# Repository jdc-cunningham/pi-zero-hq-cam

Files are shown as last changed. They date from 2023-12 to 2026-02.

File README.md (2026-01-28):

### About

#### Ver 1.1.0

A pi zero (1/2) camera body using the hq camera

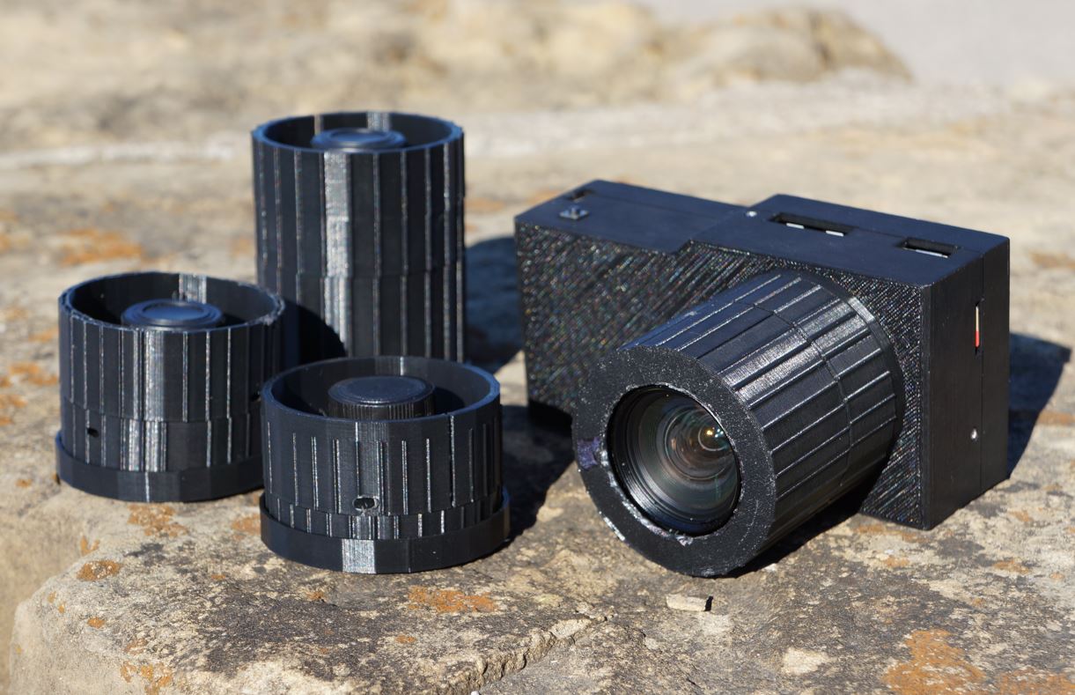
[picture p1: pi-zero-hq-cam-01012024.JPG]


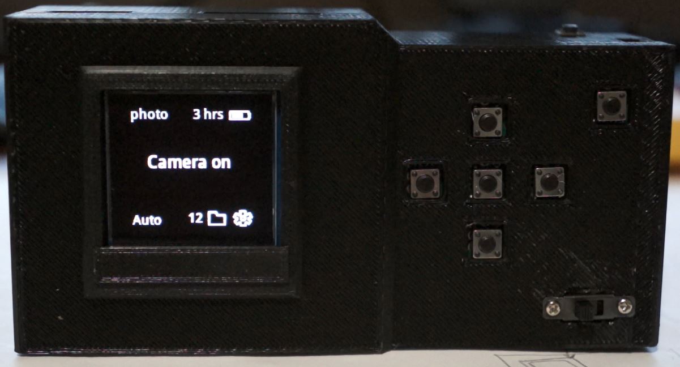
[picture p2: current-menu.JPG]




### Who is this camera for?

This camera is not about quality. You obviously can't compare this to a real camera eg. a Sony Alpha. This camera is about writing your own software/a stepping stone for other camera designs.

#### Example photo

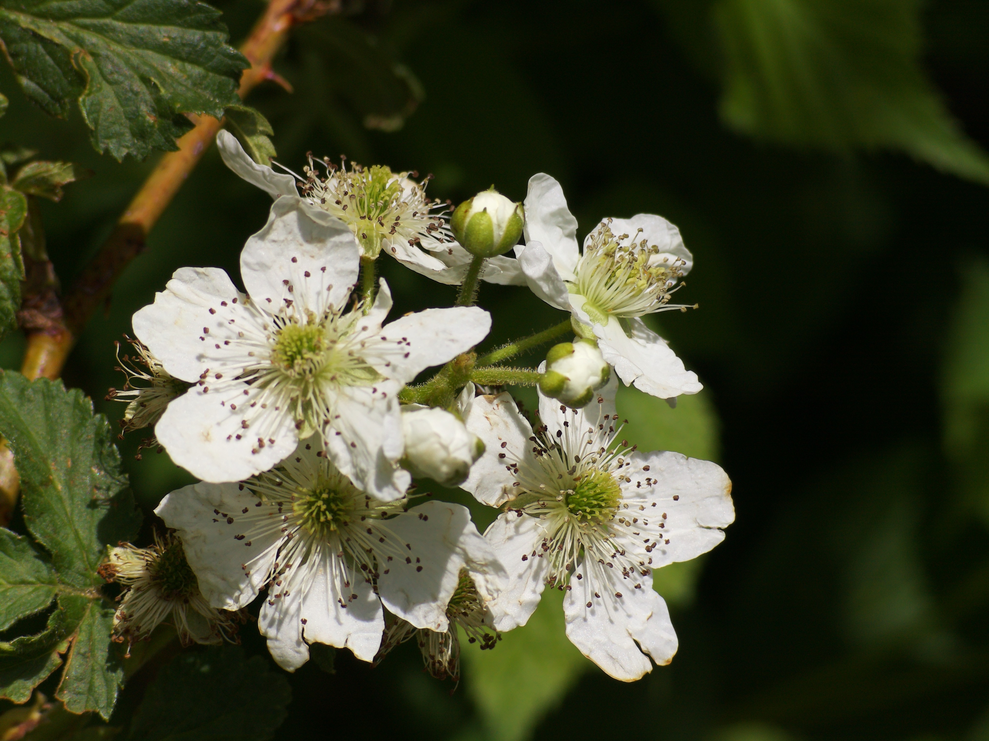
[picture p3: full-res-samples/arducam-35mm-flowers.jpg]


[full res samples](./full-res-samples/)

### Features

[See list](./camera/software/FEATURES.md) and [Changelog](./CHANGELOG.md)

### Estimated cost

$93.00 (no lens, major components only)

See `/camera/hardware` folder for more info

### Disclaimer

The 5V 1A micro usb charger's discharge cut off is very low around 2.5V, keep that in mind depending on your battery.

### Note

Refer to the [modular pi cam's software](https://github.com/jdc-cunningham/modular-pi-cam/tree/master/cameras/pi-zero/large-display/software) which is more current than this.

Eventually [pelicam](https://github.com/jdc-cunningham/pelicam) will be the general purpose DIY camera software

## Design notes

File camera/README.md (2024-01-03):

### About

- body (3D models)
- hardware (wiring diagrams)
- software (code)

### Lenses used so far

- Cytron 12mm CS mount F1.8 (prime)
- Cytron 35mm C mount F1.7 to F16 (prime)
- Amazon Sonew 5mm C mount F1.6 to F16 (prime)
- Utronics Arducam 8-50mm c-mount F1.4 adjustable (zoom)

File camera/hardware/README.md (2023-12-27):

### Parts list

- $15.00 Pi Zero W
- $75.00 Raspberry Pi HQ Camera
- $2.00 720mAh 1S Lipo
- $0.80 DC-DC boost converter
- $0.80 5V 1A usb charger
- $0.12 LD33V step down converter
- $19.00 1.5" RGB OLED
- $60.00 35mm lens
- $32 12mm lens
- $60 5mm lens
- $10 GY-91 10-axis IMU

#### Alternate parts

- $9 18650 cell - 3400mAh 4.9A discharge
- $14.33 mEZD41503A-A step-up converter 5V@3A

M1.7*6 screws

### Part layout

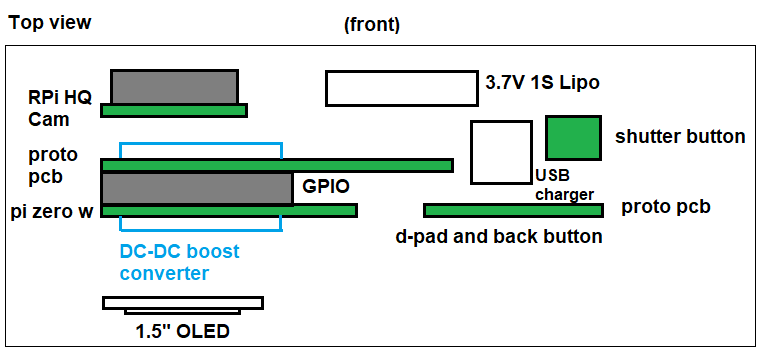
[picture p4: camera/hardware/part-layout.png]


### Pin out/wiring

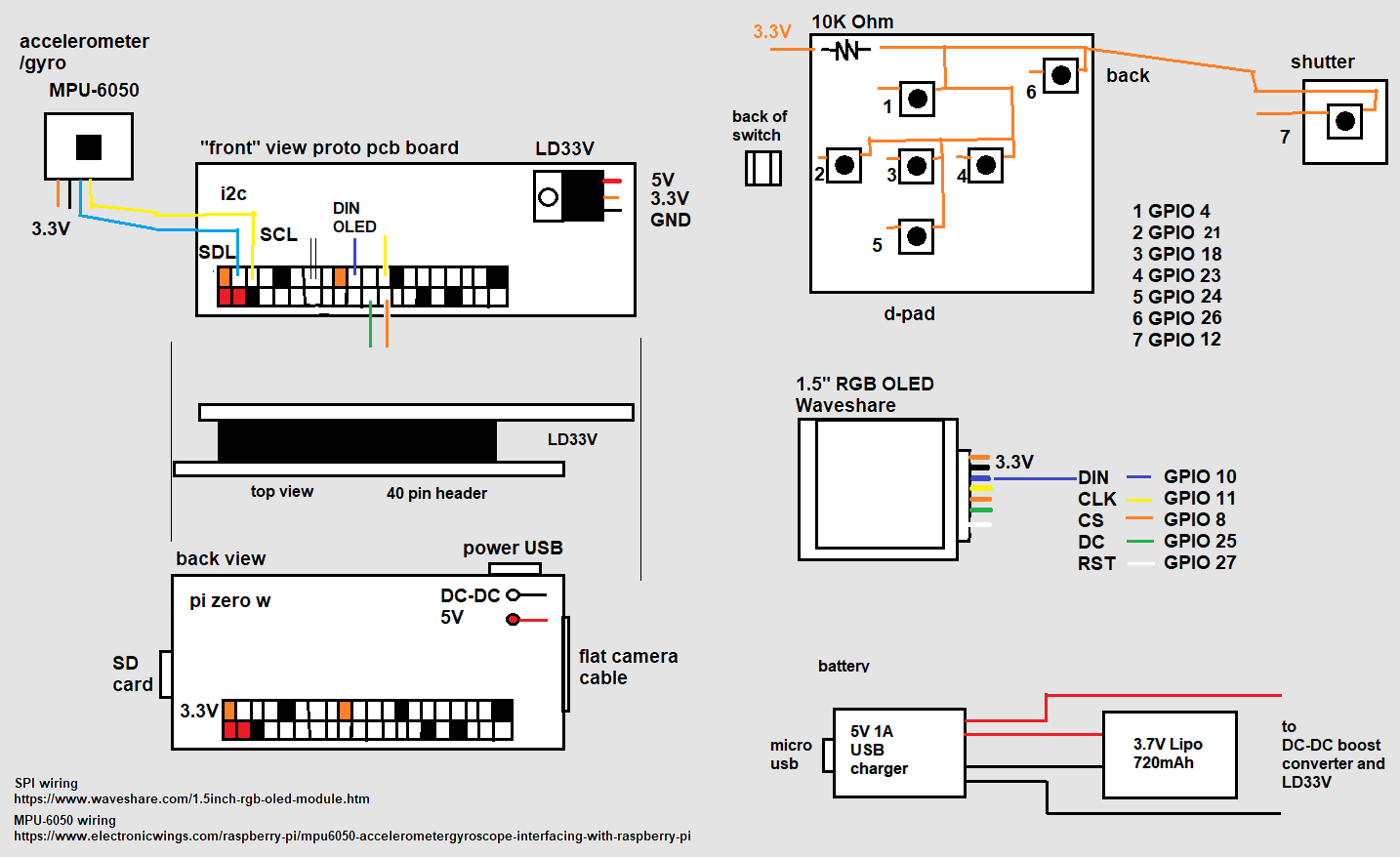
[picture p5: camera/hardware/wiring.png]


### D-pad, back and shutter buttons

### Pi Zero (1/2) GPIO mappings

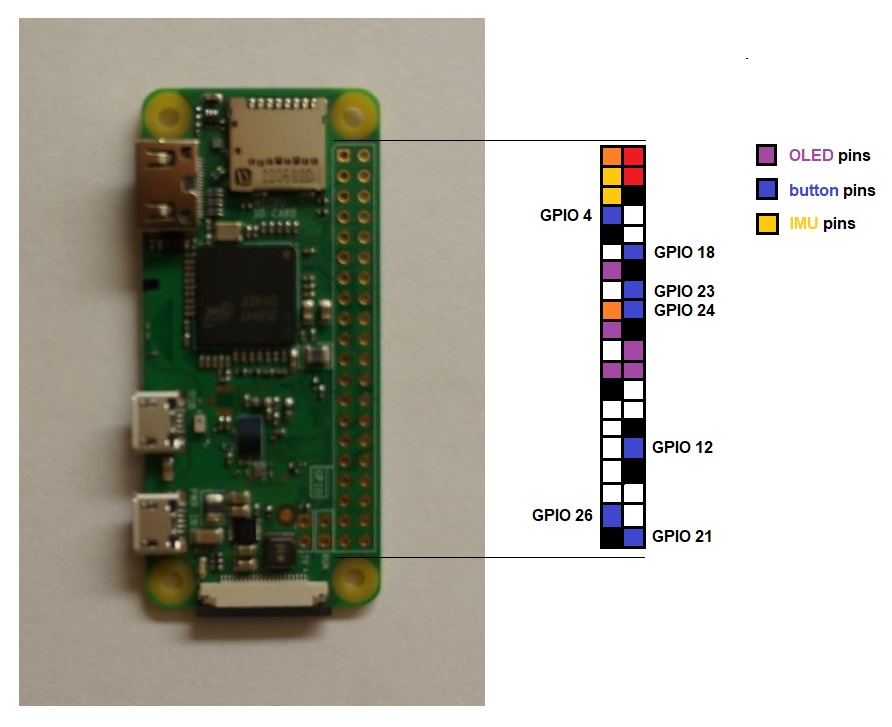
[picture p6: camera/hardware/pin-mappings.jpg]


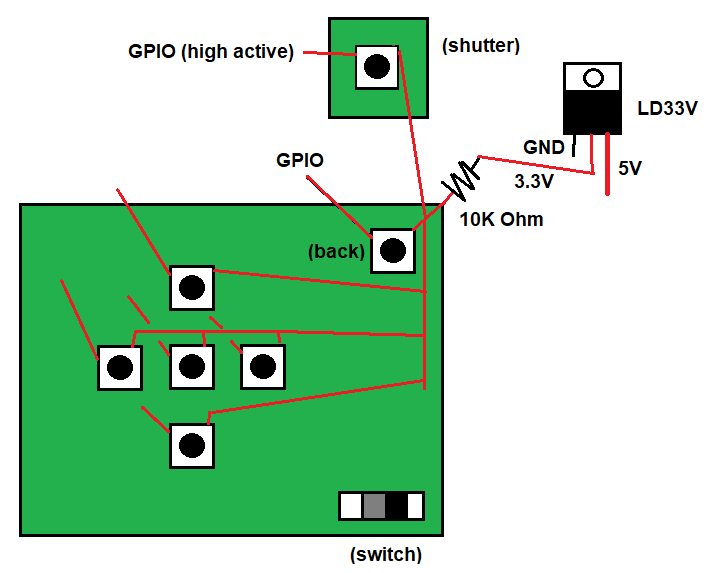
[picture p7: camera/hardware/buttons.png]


### Assembly order

- camera board (remove lens, screw, goes in from inside)
- imu (screw)
- shutter (glue)
- charger board (glue)
- battery (double sided foam tape or some glue/free floating)
- DC-DC free floating
- OLED (screws)
- push switch through (may have to bend ends temporarily, screw)
- dpad (glue)
- solder pi to hanger screw mount

join two halves together, 4 screws

### Future

A USB mic/stereo that can get plugged into the exposed USB port too add audio in/out

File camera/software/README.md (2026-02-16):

### Current code overview

See the video below

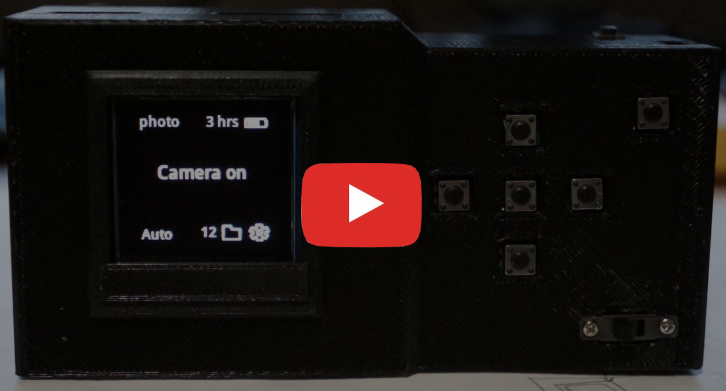
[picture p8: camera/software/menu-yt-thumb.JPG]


### Note on FPS

Please note that this code uses image capture vs. streaming which may be way faster. Check out this [mjpeg_server sample code](https://github.com/raspberrypi/picamera2/blob/main/examples/mjpeg_server.py).

### Deps

- need SPI enabled (raspi-config)
- need pip3, smbus (via pip)

### Boot script

There is a boot script that runs `main.py` in the `software` folder

It uses systemd, see the basic service file below below (systemd service)

Create a file named `pi-cam.service` in the `/etc/systemd/system/` folder

```
[Unit]
Description=Start Pi Cam
After=multi-user.target

[Service]
Type=idle
WorkingDirectory=/home/pi/pi-zero-hq-cam/camera/software
User=pi
ExecStart=/usr/bin/python3 /home/pi/pi-zero-hq-cam/camera/software/main.py
Restart=no

[Install]
WantedBy=multi-user.target
Commands for myself
```

Add the service

```
$sudo nano /etc/systemd/system/pi-cam.service
$sudo systemctl enable pi-cam.service
$sudo systemctl daemon-reload
$sudo systemctl restart pi-cam.service
```

Verify it's working with

`$sudo systemctl status pi-cam.service`

### Development notes

As of this time I have not found a way to mount/develop against the Pi. I also have not mocked the features eg. OLED, etc... to run on say a Windows computer.

I am using SFTP to edit files on the pi and then run the code via ssh session

### Battery profiling

`*/5 * * * * /usr/bin/python /home/pi/pi-zero-hq-cam/camera/software/cron_battery_ticker.py >> /home/pi/cron-battery-ticker.log 2>&1`

Verify python binary location via `$which python`

There is a Sqlite database `battery.db` that keeps track of the camera's uptime and a CRON job that increments a DB entry every 5 minutes.

In the settings menu there is a `battery profiler` function which you would run after fully charging your pi cam.

It is a loose estimate since it does not reflect how many times the user has turned the live preview on/off... it's about 75% of max capacity... based 50% testing eg. 50% preview on/off before camera dies + 25% of that to be under 80% battery usage.

I had measured some current draw values before based on what the camera is doing but I did not do a good job/accurately do it, plus the electronics changed since then. But the highest current draw is during live camera preview eg. around 600mA. For reference the pi zero 1 would draw around 65mA during idle.

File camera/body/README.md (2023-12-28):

### Print times

- 8 hrs body front
- 6 hrs body back
- 35mm aperture ring - 2.5 hrs
- 35mm focus ring - 4.5 hrs

20% infill, supports, PLA, 50mm/s print speed

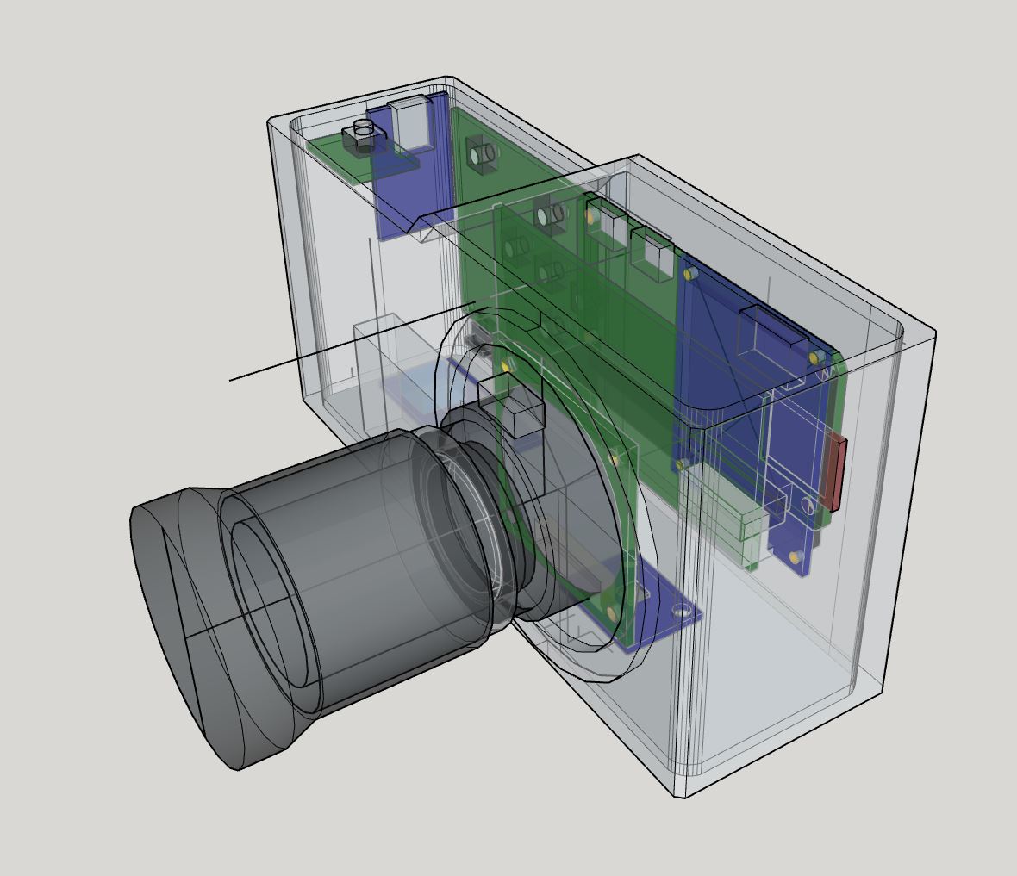
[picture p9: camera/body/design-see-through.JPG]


### Lenses

- 5mm sonew
  - this is the best "all around" lens since it's 27.5mm full frame equivalent
- 12mm arducam
  - this is used as a macro lens
- 35mm arducam
  - narrow due to the 5.5 crop factor
- 8-50mm arducam
  - this works best with the Arducam camera IMX477 camera
  - depending on which adapter is used the lens works better close or far eg. rpi adapter vs. 2 c-cs adapters (hence multiple stl files)

The 8-50mm uses 2 ring adapters (shorter). The other 3 use the RPi HQ Cam ring adapter.

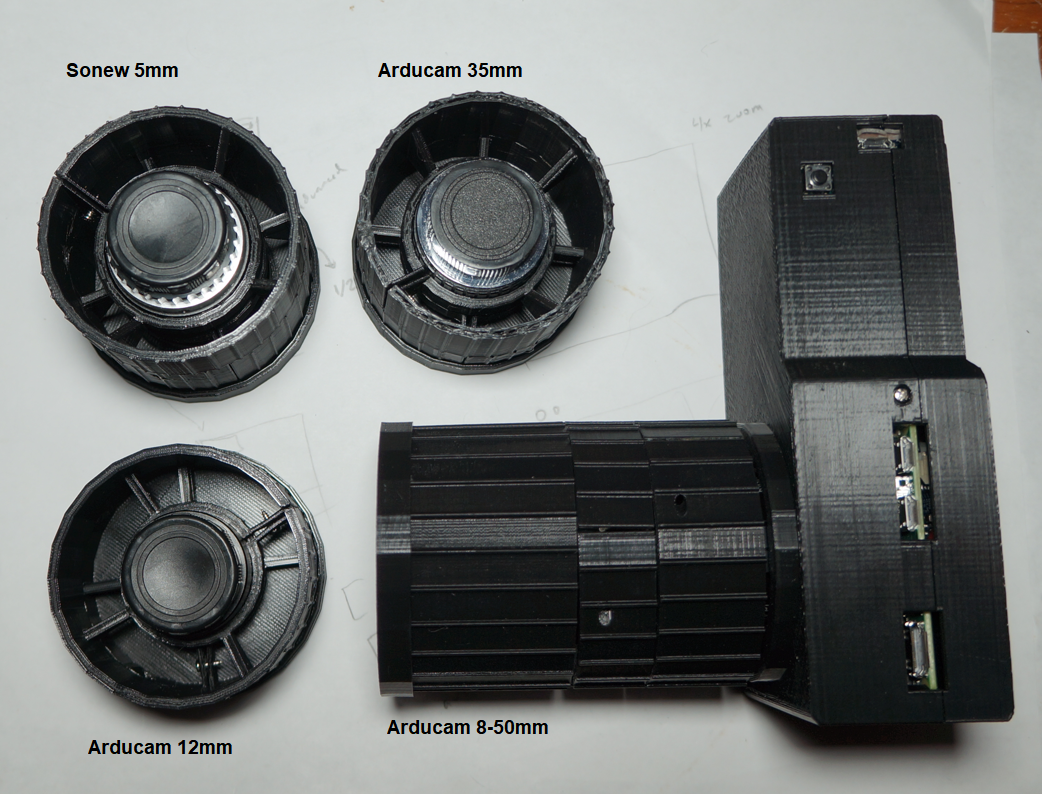
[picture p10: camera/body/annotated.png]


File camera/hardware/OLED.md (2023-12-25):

wiring guide

https://www.waveshare.com/1.5inch-rgb-oled-module.htm

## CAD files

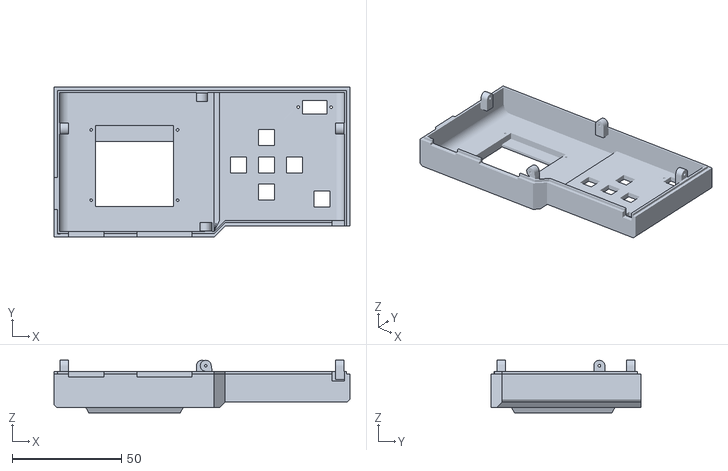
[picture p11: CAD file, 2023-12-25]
camera/body/3d-models/stls/camera-body/body-back.stl
135.2 x 68.6 x 24.0

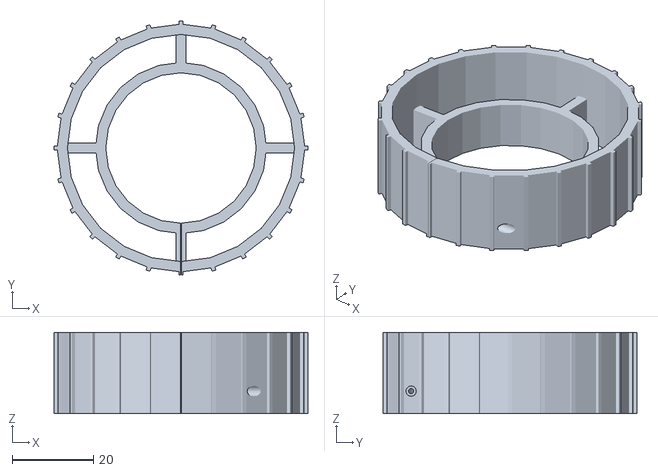
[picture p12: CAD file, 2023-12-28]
camera/body/3d-models/stls/lens/8-50mm-arducam-telephoto-focus-ring-1-rpi-adapter-ring.stl
62.5 x 62.5 x 20.0

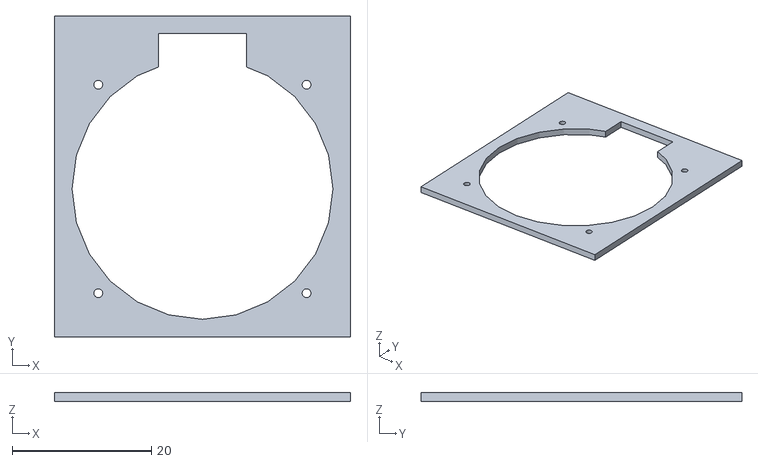
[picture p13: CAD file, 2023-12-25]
camera/body/3d-models/stls/test-fit-camera.stl
42.6 x 46.1 x 1.27

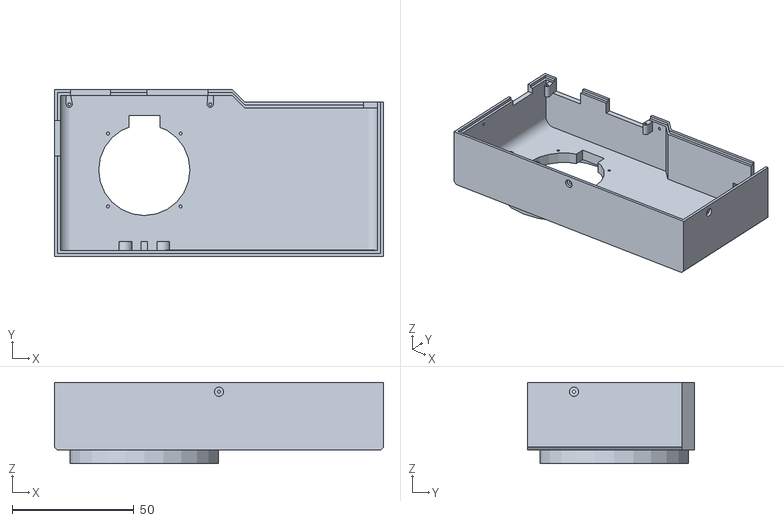
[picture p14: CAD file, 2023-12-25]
camera/body/3d-models/stls/camera-body/body-front.stl
135.2 x 68.6 x 33.3

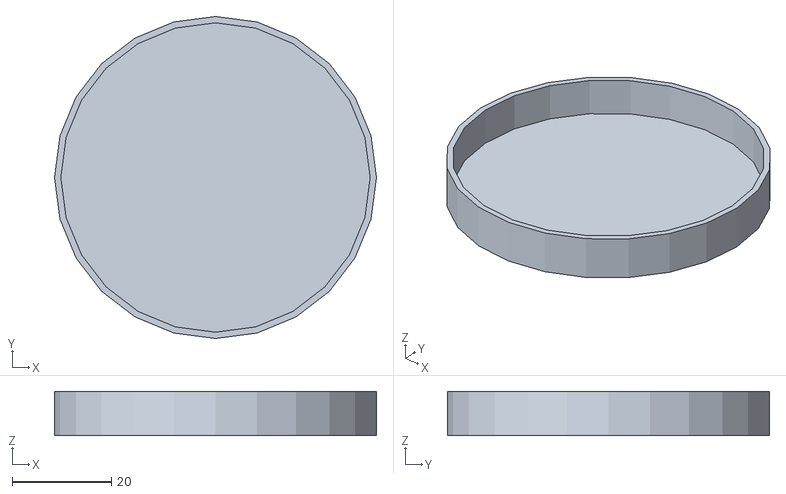
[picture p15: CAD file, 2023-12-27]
camera/body/3d-models/stls/lens/12mm-arducam-lens-cap.stl
64.8 x 64.8 x 8.89

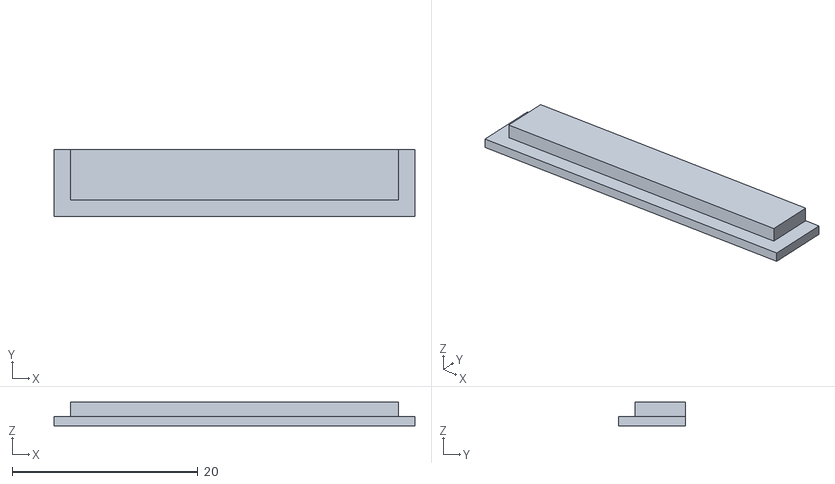
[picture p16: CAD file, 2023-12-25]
camera/body/3d-models/stls/oled-bottom-cover.stl
38.9 x 7.21 x 2.54

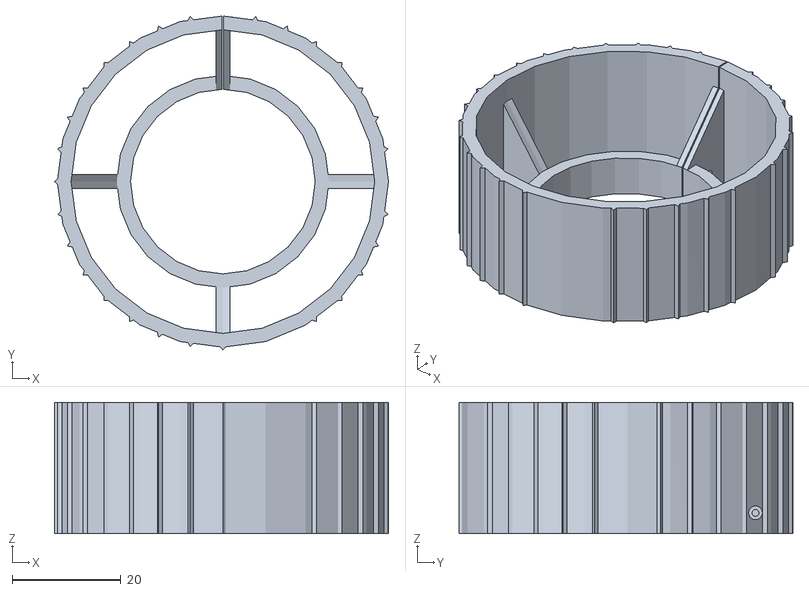
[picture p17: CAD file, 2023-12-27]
camera/body/3d-models/stls/lens/35mm-arducam-aperture-ring.stl
61.5 x 61.5 x 24.1

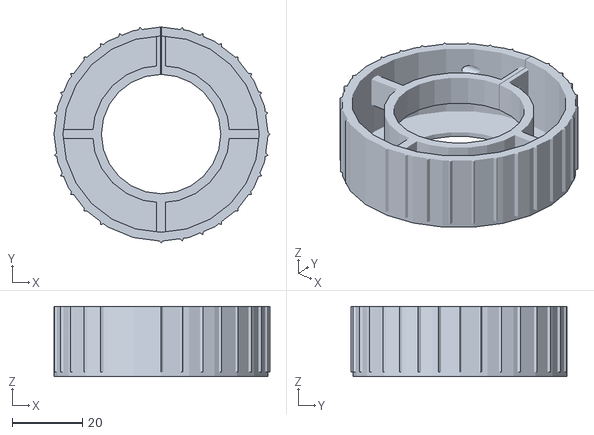
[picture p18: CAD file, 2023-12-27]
camera/body/3d-models/stls/lens/35mm-arducam-focus-ring.stl
61.5 x 61.5 x 20.0

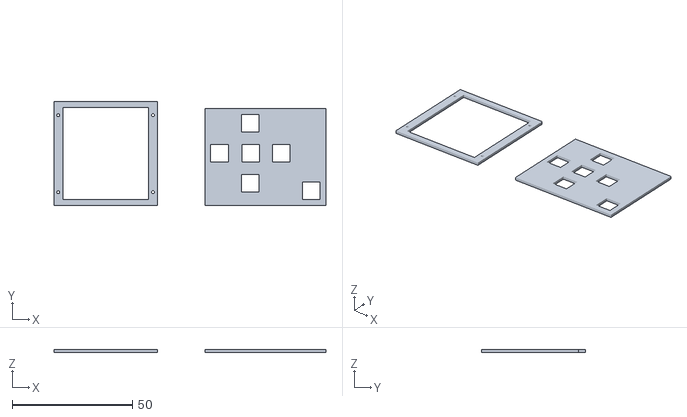
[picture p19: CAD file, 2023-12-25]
camera/body/3d-models/stls/test-fit-back.stl
113.3 x 43.4 x 1.29

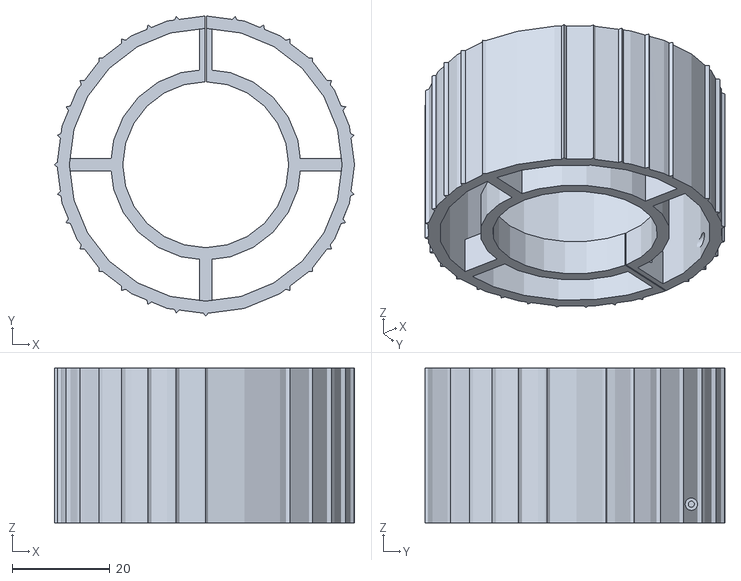
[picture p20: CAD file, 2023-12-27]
camera/body/3d-models/stls/lens/35mm-barrel-ring-aperture.stl
61.5 x 61.5 x 31.7

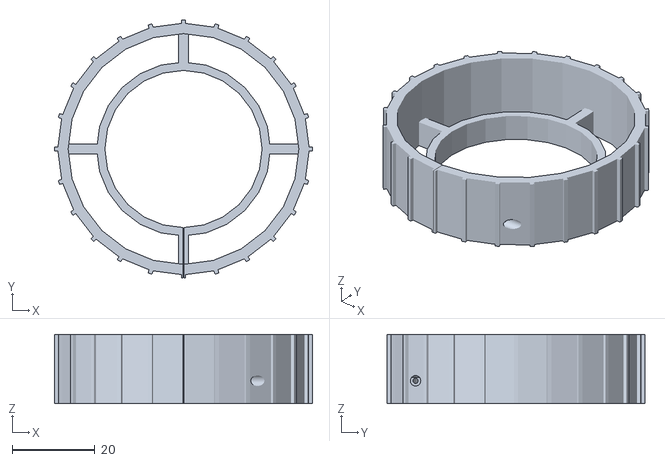
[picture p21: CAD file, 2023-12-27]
camera/body/3d-models/stls/lens/8-50mm-arducam-telephoto-aperture-ring-2-adapter-ring.stl
62.5 x 62.5 x 16.8

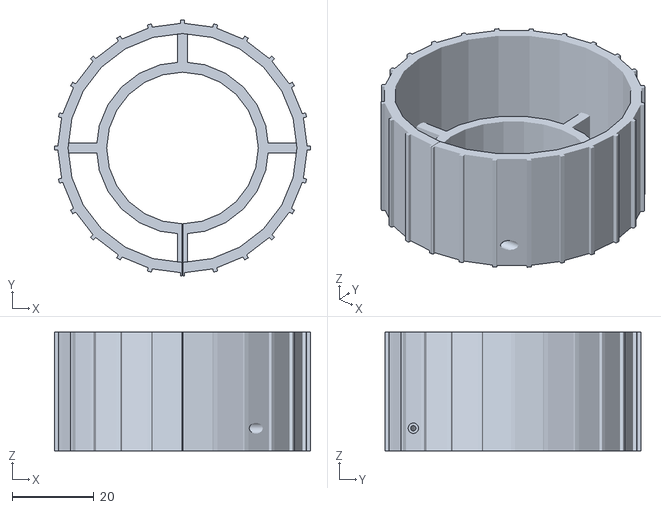
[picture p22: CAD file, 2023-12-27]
camera/body/3d-models/stls/lens/8-50mm-arducam-telephoto-focus-ring-2-adapter-ring.stl
62.5 x 62.5 x 29.0

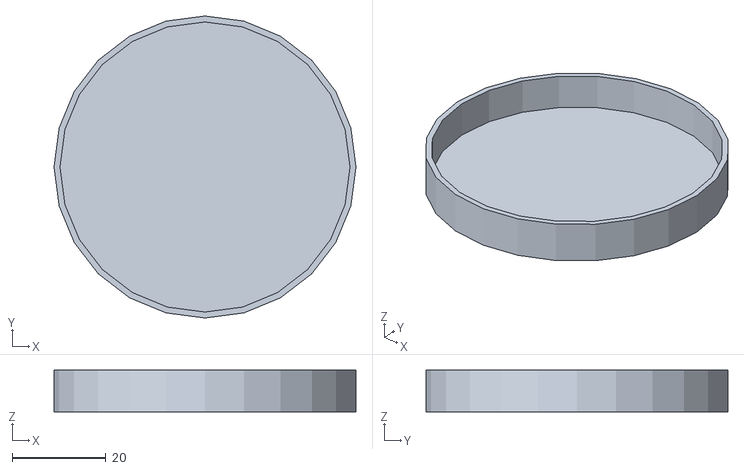
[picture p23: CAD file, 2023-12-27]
camera/body/3d-models/stls/lens/35mm-arducam-lens-cap.stl
64.3 x 64.3 x 8.89

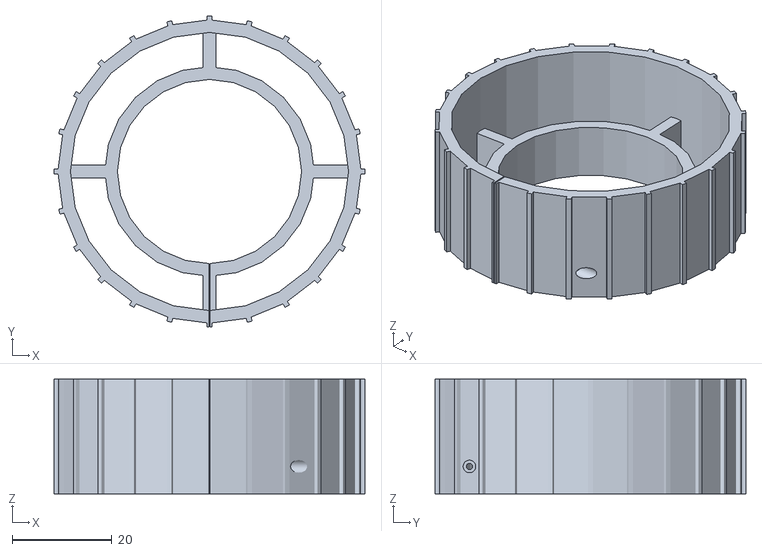
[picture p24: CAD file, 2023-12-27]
camera/body/3d-models/stls/lens/8-50mm-arducam-telephoto-focus-ring.stl
62.5 x 62.5 x 23.1

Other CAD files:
camera/body/3d-models/stls/lens/12mm-arducam-aperture-ring.stl
camera/body/3d-models/stls/lens/5mm-sonew-lens-cap.stl
camera/body/3d-models/stls/lens/8-50mm-arducam-telephoto-zoom-ring.stl
camera/body/3d-models/stls/lens/8-50mm-arducam-telephoto-lens-cap.stl
camera/body/3d-models/sketchup/camera-body/body-0.skp
camera/body/3d-models/sketchup/camera-body/body-back.skp
camera/body/3d-models/sketchup/camera-body/body-front.skp
camera/body/3d-models/sketchup/camera-body/body-seam-design.skp
camera/body/3d-models/sketchup/camera-body/body.skp
camera/body/3d-models/sketchup/lens/12mm-arducam-aperture-ring.skp
camera/body/3d-models/sketchup/lens/12mm-arducam-focus-ring.skp
camera/body/3d-models/sketchup/lens/12mm-arducam-lens-cap.skp
camera/body/3d-models/sketchup/lens/35mm-arducam-aperture-ring.skp
camera/body/3d-models/sketchup/lens/35mm-arducam-lens-cap.skp
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

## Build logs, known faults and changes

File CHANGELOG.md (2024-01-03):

### 1.1.0 (01/02/2024)

[video](https://youtu.be/kRxcRApp_eA)

- added battery profiler (software eg. CRON)
- timelapse (no menu, fixed at 5 mins)

### 1.0.0 (12/27/2023)

[video](https://www.youtube.com/watch?v=E31nRjYFxPQ)

- first menu design
- 4x zoom-crop panning
- video mode
- file view demo
- settings with raw telemetry dump

### 0.0.1 (12/19/2023)

[video](https://youtu.be/CfI78B7uEhQ?si=M_CHCzKxf_PONVFb&t=160)

- able to show live preview
- take photo
- no menu

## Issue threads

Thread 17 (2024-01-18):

Fix buggy camera state

jdc-cunningham, 2024-01-18:
- [ ] figure out failed writes eg. photos with 0 bytes
- [ ] after zooming in (4x) during live preview and taking a photo, camera no longer works, have to restart

jdc-cunningham, 2024-01-19:
Maybe try this code (about explicitly opening a file)

I will also add a random alphanum string to the epoch time since the clock seems to go backwards from the RPi turning on/off often

https://raspberrypi.stackexchange.com/questions/74126/captured-image-file-from-picamera-is-0kb-why

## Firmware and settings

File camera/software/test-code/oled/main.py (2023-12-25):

# -*- coding:UTF-8 -*-

import io
import time
from picamera2 import Picamera2

#--------------Driver Library-----------------#
import RPi.GPIO as GPIO
import OLED_Driver as OLED

#--------------Image Library---------------#
from PIL  import Image
from PIL import ImageDraw
from PIL import ImageFont
from PIL import ImageColor

#-------------Test Display Functions---------------#

def Test_Text():
    image = Image.new("RGB", (OLED.SSD1351_WIDTH, OLED.SSD1351_HEIGHT), "BLACK")
    draw = ImageDraw.Draw(image)
    font = ImageFont.truetype('cambriab.ttf',24)

    draw.text((0, 12), 'WaveShare', fill = "BLUE", font = font)
    draw.text((0, 36), 'Electronic', fill = "BLUE",font = font)
    draw.text((20, 72), '1.5 inch', fill = "CYAN", font = font)
    draw.text((10, 96), 'R', fill = "RED", font = font)
    draw.text((25, 96), 'G', fill = "GREEN", font = font)
    draw.text((40, 96), 'B', fill = "BLUE", font = font)
    draw.text((55, 96), ' OLED', fill = "CYAN", font = font)

    OLED.Display_Image(image)

def Draw_Text(text):
    image = Image.new("RGB", (OLED.SSD1351_WIDTH, OLED.SSD1351_HEIGHT), "BLACK")
    draw = ImageDraw.Draw(image)
    font = ImageFont.truetype('cambriab.ttf',24)

    draw.text((55, 96), ' OLED', fill = "WHITE", font = font)

    OLED.Display_Image(image)


def Test_Pattern():
    image = Image.new("RGB", (OLED.SSD1351_WIDTH, OLED.SSD1351_HEIGHT), "BLACK")
    draw = ImageDraw.Draw(image)

    draw.line([(0,8), (127,8)],   fill = "RED",    width = 16)
    draw.line([(0,24),(127,24)],  fill = "YELLOW", width = 16)
    draw.line([(0,40),(127,40)],  fill = "GREEN",  width = 16)
    draw.line([(0,56),(127,56)],  fill = "CYAN",   width = 16)
    draw.line([(0,72),(127,72)],  fill = "BLUE",   width = 16)
    draw.line([(0,88),(127,88)],  fill = "MAGENTA",width = 16)
    draw.line([(0,104),(127,104)],fill = "BLACK",  width = 16)
    draw.line([(0,120),(127,120)],fill = "WHITE",  width = 16)

    OLED.Display_Image(image)


def Test_Lines():
    image = Image.new("RGB", (OLED.SSD1351_WIDTH, OLED.SSD1351_HEIGHT), "BLACK")
    draw = ImageDraw.Draw(image)

    for x in range(0, int((OLED.SSD1351_WIDTH-1)/2), 6):
        draw.line([(0, 0), (x, OLED.SSD1351_HEIGHT - 1)], fill = "RED", width = 1)
        draw.line([(0, 0), ((OLED.SSD1351_WIDTH-1) - x, OLED.SSD1351_HEIGHT - 1)], fill = "RED", width = 1)
        draw.line([(0, 0), (OLED.SSD1351_WIDTH - 1, x)], fill = "RED", width = 1)
        draw.line([(0, 0), (OLED.SSD1351_WIDTH - 1, (OLED.SSD1351_HEIGHT-1) - x)], fill = "RED", width = 1)
        OLED.Display_Image(image)
    OLED.Delay(250)
    draw.rectangle([0, 0, OLED.SSD1351_WIDTH - 1, OLED.SSD1351_HEIGHT - 1], fill = "BLACK", outline = "BLACK")

    for x in range(0, int((OLED.SSD1351_WIDTH-1)/2), 6):
        draw.line([(OLED.SSD1351_WIDTH - 1, 0), (x, OLED.SSD1351_HEIGHT - 1)], fill = "YELLOW", width = 1)
        draw.line([(OLED.SSD1351_WIDTH - 1, 0), (x + int((OLED.SSD1351_WIDTH-1)/2), OLED.SSD1351_HEIGHT - 1)], fill = "YELLOW", width = 1)
        draw.line([(OLED.SSD1351_WIDTH - 1, 0), (0, x)], fill = "YELLOW", width = 1)
        draw.line([(OLED.SSD1351_WIDTH - 1, 0), (0, x + int((OLED.SSD1351_HEIGHT-1)/2))], fill = "YELLOW", width = 1)
        OLED.Display_Image(image)
    OLED.Delay(250)
    draw.rectangle([0, 0, OLED.SSD1351_WIDTH - 1, OLED.SSD1351_HEIGHT - 1], fill = "BLACK", outline = "BLACK")

    for x in range(0, int((OLED.SSD1351_WIDTH-1)/2), 6):
        draw.line([(0, OLED.SSD1351_HEIGHT - 1), (x, 0)], fill = "BLUE", width = 1)
        draw.line([(0, OLED.SSD1351_HEIGHT - 1), (x + int((OLED.SSD1351_WIDTH-1)/2), 0)], fill = "BLUE", width = 1)
        draw.line([(0, OLED.SSD1351_HEIGHT - 1), (OLED.SSD1351_WIDTH - 1, x)], fill = "BLUE", width = 1)
        draw.line([(0, OLED.SSD1351_HEIGHT - 1), (OLED.SSD1351_WIDTH - 1, x + (OLED.SSD1351_HEIGHT-1)/2)], fill = "BLUE", width = 1)
        OLED.Display_Image(image)
    draw.rectangle([0, 0, OLED.SSD1351_WIDTH - 1, OLED.SSD1351_HEIGHT - 1], fill = "BLACK", outline = "BLACK")
    OLED.Delay(250)

    for x in range(0, int((OLED.SSD1351_WIDTH-1)/2), 6):
        draw.line([(OLED.SSD1351_WIDTH - 1, OLED.SSD1351_HEIGHT - 1), (x, 0)], fill = "GREEN", width = 1)
        draw.line([(OLED.SSD1351_WIDTH - 1, OLED.SSD1351_HEIGHT - 1), (x + int((OLED.SSD1351_WIDTH-1)/2), 0)], fill = "GREEN", width = 1)
        draw.line([(OLED.SSD1351_WIDTH - 1, OLED.SSD1351_HEIGHT - 1), (0, x)], fill = "GREEN", width = 1)
        draw.line([(OLED.SSD1351_WIDTH - 1, OLED.SSD1351_HEIGHT - 1), (0, x + int((OLED.SSD1351_HEIGHT-1)/2))], fill = "GREEN", width = 1)
        OLED.Display_Image(image)
    draw.rectangle([0, 0, OLED.SSD1351_WIDTH - 1, OLED.SSD1351_HEIGHT - 1], fill = "BLACK")


def Test_HV_Lines():
    image = Image.new("RGB", (OLED.SSD1351_WIDTH, OLED.SSD1351_HEIGHT), "BLACK")
    draw = ImageDraw.Draw(image)

    for y in range(0, OLED.SSD1351_HEIGHT - 1, 5):
        draw.line([(0, y), (OLED.SSD1351_WIDTH - 1, y)], fill = "WHITE", width = 1)
    OLED.Display_Image(image)
    OLED.Delay(250)
    for x in range(0, OLED.SSD1351_WIDTH - 1, 5):
        draw.line([(x, 0), (x, OLED.SSD1351_HEIGHT - 1)], fill = "WHITE", width = 1)
    OLED.Display_Image(image)


def Test_Rects():
    image = Image.new("RGB", (OLED.SSD1351_WIDTH, OLED.SSD1351_HEIGHT), "BLACK")
    draw = ImageDraw.Draw(image)

    for x in range(0, int((OLED.SSD1351_WIDTH-1)/2), 6):
        draw.rectangle([(x, x), (OLED.SSD1351_WIDTH- 1 - x, OLED.SSD1351_HEIGHT-1 - x)], fill = None, outline = "WHITE")
    OLED.Display_Image(image)


def Test_FillRects(): 
    image = Image.new("RGB", (OLED.SSD1351_WIDTH, OLED.SSD1351_HEIGHT), "BLACK")
    draw = ImageDraw.Draw(image)

    for x in range(OLED.SSD1351_HEIGHT-1, int((OLED.SSD1351_HEIGHT-1)/2), -6):
        draw.rectangle([(x, x), ((OLED.SSD1351_WIDTH-1) - x, (OLED.SSD1351_HEIGHT-1) - x)], fill = "BLUE", outline = "BLUE")
        draw.rectangle([(x, x), ((OLED.SSD1351_WIDTH-1) - x, (OLED.SSD1351_HEIGHT-1) - x)], fill = None, outline = "YELLOW")
    OLED.Display_Image(image)


def Test_Circles():
    image = Image.new("RGB", (OLED.SSD1351_WIDTH, OLED.SSD1351_HEIGHT), "BLACK")
    draw = ImageDraw.Draw(image)

    draw.ellipse([(0, 0), (OLED.SSD1351_WIDTH - 1, OLED.SSD1351_HEIGHT - 1)], fill = "BLUE", outline = "BLUE")
    OLED.Display_Image(image)
    OLED.Delay(500)
    for r in range(0, int(OLED.SSD1351_WIDTH/2) + 4, 4):
        draw.ellipse([(r, r), ((OLED.SSD1351_WIDTH-1) - r, (OLED.SSD1351_HEIGHT-1) - r)], fill = None, outline = "YELLOW")
    OLED.Display_Image(image)


def Test_Triangles():
    image = Image.new("RGB", (OLED.SSD1351_WIDTH, OLED.SSD1351_HEIGHT), "BLACK")
    draw = ImageDraw.Draw(image)

    for i in range(0, int(OLED.SSD1351_WIDTH/2), 4):
        draw.line([(i, OLED.SSD1351_HEIGHT - 1 - i), (OLED.SSD1351_WIDTH/2, i)], fill = (255 - i*4, i*4, 255 - i*4), width = 1)
        draw.line([(i, OLED.SSD1351_HEIGHT - 1 - i), (OLED.SSD1351_WIDTH - 1 - i, OLED.SSD1351_HEIGHT - 1 - i)], fill = (i*4, i*4 ,255 - i*4), width = 1)
        draw.line([(OLED.SSD1351_WIDTH - 1 - i, OLED.SSD1351_HEIGHT - 1 - i), (OLED.SSD1351_WIDTH/2, i)], fill = (i*4, 255 - i*4, i*4), width = 1)
        OLED.Display_Image(image)


def Display_Picture(File_Name):
    image = Image.open(File_Name)
    OLED.Display_Image(image)

#----------------------MAIN-------------------------#
try:

    def main():

        #-------------OLED Init------------#
        OLED.Device_Init()

        # try pi camera buffer
        # this is rancid, just testing

        picam2 = Picamera2()
        config = picam2.create_still_configuration(main={"size": (128, 128)})
        picam2.configure(config)
        picam2.start()

        while (True):
            pil_img = picam2.capture_image()
            OLED.Display_Buffer(pil_img.load())


    if __name__ == '__main__':
        main()

# except Exception as e:
except:
    # print(e)
    print("\r\nEnd")
    OLED.Clear_Screen()
    GPIO.cleanup()

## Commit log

2023-12-25 0.0.1
    mvp
    [1.5-oled.skp, 5mm-barrel-ring-aperture.stl, 5mm-barrel-ring-focus.stl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]
2023-12-28 add lens part, add some notes
    [8-50mm-arducam-telephoto-focus-ring-1-rpi-adapter-ring.skp, 8-50mm-arducam-telephoto-focus-ring-1-rpi-adapter-ring.stl]
2024-01-03 v1.1.0 battery profiler and timelapse (#12)
    1.1.0 - battery profiler, timelapse
    [1.5-oled.skp, 12mm-arducam-aperture-ring.skp, 12mm-arducam-aperture-ring.stl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]
2024-01-18 add sample photo (#16)
    update sample photo on readme
2024-05-06 add sample image for 16mm blue ring telephoto lens (#19)
2024-05-08 add new photo for 35mm (#21)
2026-01-28 Update README.md (#24)
    Show lower price, don't include lens count
